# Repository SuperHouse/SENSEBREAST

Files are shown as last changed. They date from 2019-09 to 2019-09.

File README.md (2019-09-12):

SenseBreast Hat for Raspberry Pi
================================
Copyright 2019 SuperHouse Automation Pty Ltd www.superhouse.tv  

Multiple sensors integrated into a Raspberry Pi hat format for use in
construction of a prosthetic breast as part of the Sense Breast project.
Sensor data can be logged locally and accessed via WiFi, or published
to a data broker such as MQTT.

FEATURES
--------

 * BME680 temperature, pressure, humidity, and VOC gas sensor.
 * 9-DOF IMU with I2C interface.
 * Connector for external heart rate sensor.

INSTALLATION
------------
The design is saved as an EAGLE project. EAGLE PCB design software is
available from www.cadsoftusa.com free for non-commercial use. To use
this project download it and place the directory containing these files
into the "eagle" directory on your computer. Then open EAGLE and
navigate to the project.

DISTRIBUTION
------------
The specific terms of distribution of this project are governed by the
license referenced below.

LICENSE
-------
Licensed under the TAPR Open Hardware License (www.tapr.org/OHL).
The "license" folder within this repository also contains a copy of
this license in plain text format.

CREDITS
-------
Software and concept by Kathy Reid
Hardware by Jonathan Oxer <jon@oxer.com.au>

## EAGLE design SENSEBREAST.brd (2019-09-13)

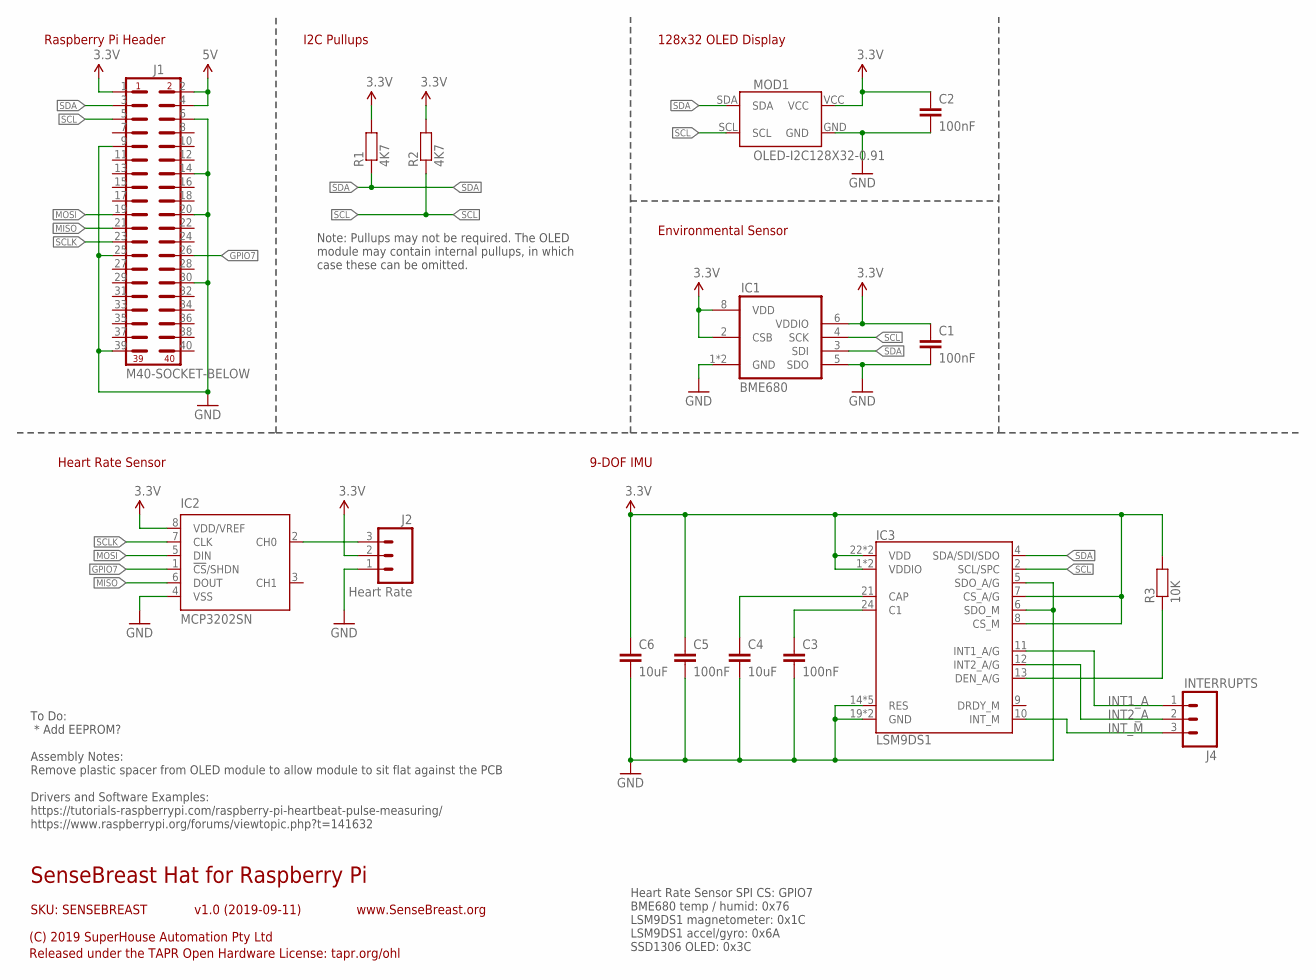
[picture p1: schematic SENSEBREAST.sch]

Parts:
C1, C2, C3, C5: 100nF; C0603
C4, C6: 10uF; C0805
IC1: BME680
IC2: MCP3202SN; SO-08
IC3: LSM9DS1; LGA24-8X4
J1: M40-SOCKET-BELOW; 2X20-S-BELOW
J2: Heart Rate; 1X03-S-RA
J4: INTERRUPTS; 1X03
MOD1: OLED-I2C128X32-0.91; OLED-128X32-0.91
R1, R2: 4K7; R0603
R3: 10K; R0603

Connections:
3.3V: C1.1, C2.1, C5.1, C6.1, IC1.2 (CSB), IC1.6 (VDDIO), IC1.8 (VDD), IC2.8 (VDD/VREF), IC3.1 (VDDIO), IC3.3 (VDDIO), IC3.7 (CS_A/G), IC3.8 (CS_M), IC3.22 (VDD), IC3.23 (VDD), J1.1, J2.2, MOD1.VCC, R1.2, R2.2, R3.2
5V: J1.2, J1.4
GND: C1.2, C2.2, C3.2, C4.2, C5.2, C6.2, IC1.1 (GND), IC1.5 (SDO), IC1.7 (GND), IC2.4 (VSS), IC3.5 (SDO_A/G), IC3.6 (SDO_M), IC3.14 (RES), IC3.15 (RES), IC3.16 (RES), IC3.17 (RES), IC3.18 (RES), IC3.19 (GND), IC3.20 (GND), J1.6, J1.9, J1.14, J1.20, J1.25, J1.30, J1.39, J2.1, MOD1.GND
GPIO7: IC2.1 (!CS!/SHDN), J1.26
INT1_A: IC3.11 (INT1_A/G), J4.1
INT2_A: IC3.12 (INT2_A/G), J4.2
INT_M: IC3.10 (INT_M), J4.3
MISO: IC2.6 (DOUT), J1.21
MOSI: IC2.5 (DIN), J1.19
unnamed: IC2.2 (CH0), J2.3
unnamed: IC3.13 (DEN_A/G), R3.1
unnamed: C3.1, IC3.24 (C1)
unnamed: C4.1, IC3.21 (CAP)
SCL: IC1.4 (SCK), IC3.2 (SCL/SPC), J1.5, MOD1.SCL, R2.1
SCLK: IC2.7 (CLK), J1.23
SDA: IC1.3 (SDI), IC3.4 (SDA/SDI/SDO), J1.3, MOD1.SDA, R1.1

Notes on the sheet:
SenseBreast Hat for Raspberry Pi
v1.0 (2019-09-11)
(C) 2019 SuperHouse Automation Pty Ltd
Released under the TAPR Open Hardware License: tapr.org/ohl
www.SenseBreast.org
SKU: SENSEBREAST
Raspberry Pi Header
128x32 OLED Display
Environmental Sensor
I2C Pullups
Note: Pullups may not be required. The OLED module may contain internal pullups, in which case these can be omitted.
To Do: * Add EEPROM? Assembly Notes: Remove plastic spacer from OLED module to allow module to sit flat against the PCB Drivers and Software Examples: https://tutorials-raspberrypi.com/raspberry-pi-heartbeat-pulse-measuring/ https://www.raspberrypi.org/forums/viewtopic.php?t=141632
Heart Rate Sensor
9-DOF IMU
Heart Rate Sensor SPI CS: GPIO7 BME680 temp / humid: 0x76 LSM9DS1 magnetometer: 0x1C LSM9DS1 accel/gyro: 0x6A SSD1306 OLED: 0x3C

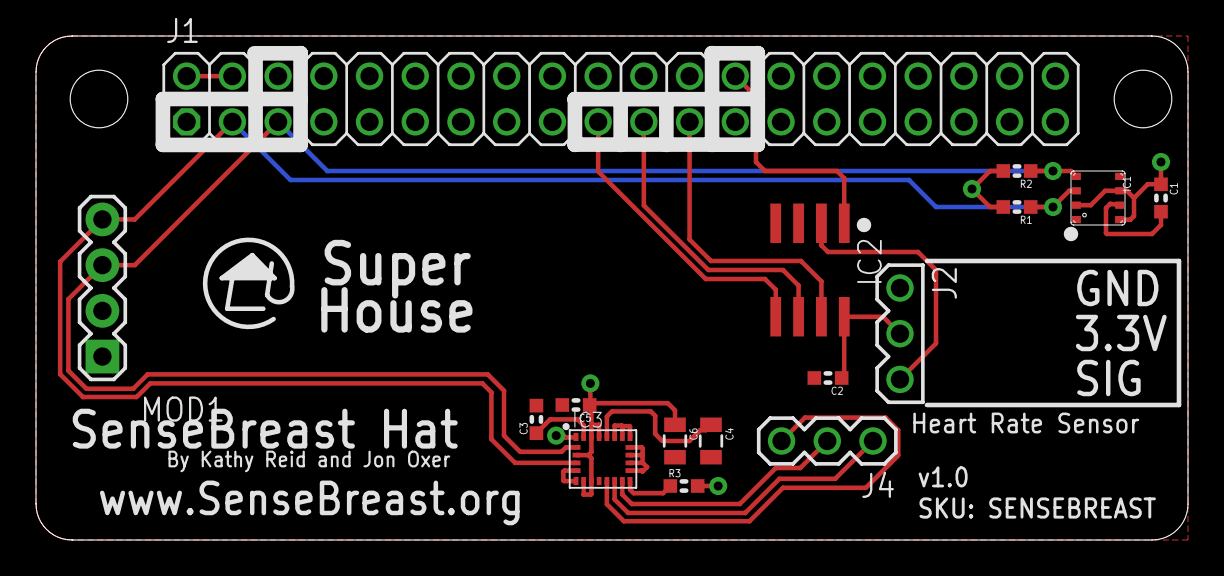
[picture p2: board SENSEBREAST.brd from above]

Board: 2 copper layers, 64.0 x 28.0 mm, 16 parts (0 on the bottom side), 16 nets.

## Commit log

2019-09-10 Initial project import
    [SENSEBREAST.brd, SENSEBREAST.sch]
2019-09-12 Replaced BME280 with BME680 to allow detection of VOC levels in the environment
    [SENSEBREAST.brd, SENSEBREAST.sch]
2019-09-13 Final routing, plus ERC and DRC for v1.0 release
    [SENSEBREAST.brd, SENSEBREAST.sch]
